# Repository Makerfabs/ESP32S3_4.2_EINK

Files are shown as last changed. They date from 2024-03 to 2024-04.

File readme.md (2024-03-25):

# ESP32 S3 4.2" EINK

```

Version:    V1.0
Author:     Vincent
Create Date:    2024/3/25
Note:

```
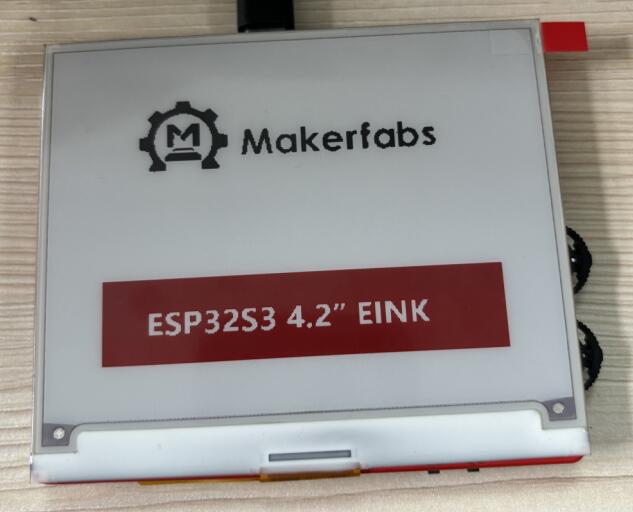
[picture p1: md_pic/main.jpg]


[toc]

# Makerfabs

[Makerfabs home page](https://www.makerfabs.com/)

[Makerfabs Wiki](https://wiki.makerfabs.com/)

# ESP32 S3 4.2" EINK
## Intruduce

Product Link ：[]() 

Wiki Link : []()

The red and black ink screen uses the ESP32S3 driver, contains an SD card slot and two three-way toggle switches.

## Feature

- Integrated ESP32 S3 2.4G WiFi and Bluetooth
- Input Voltage: 3.7V Battery or 5.0V Type-C
- Resolution: 400 * 300
- Display Color: Red / Black and White

# Code

## Compiler Options

- Use type-c use cable connect USB-TTL to PC.
- Select "ESP32 S3 DEV Module"

Libraries:
- Use 2.0.0   FS
- Use 2.0.0   Wire
- Use 1.0.0   esp32-waveshare-epd
- Use 2.0.0   SD_MMC

We used the ink screen driver provided by Waveshare and modified the pins to fit our hardware.

## Example

### fw_test

Factory firmware.
Refresh the solid color page, display the makerfabs Logo, display simple text and multi-color test, and display TF card capacity, press any key to sleep the screen.

### ebook

Read txt file in tf cards, and use switch to change page.

### pic_display

A bmp picture, binary processing, display on the screen.

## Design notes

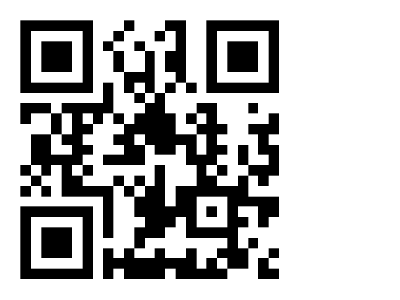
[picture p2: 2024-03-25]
example/pic_display/qr400300.bmp

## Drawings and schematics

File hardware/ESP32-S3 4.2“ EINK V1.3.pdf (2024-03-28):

# BUTTON

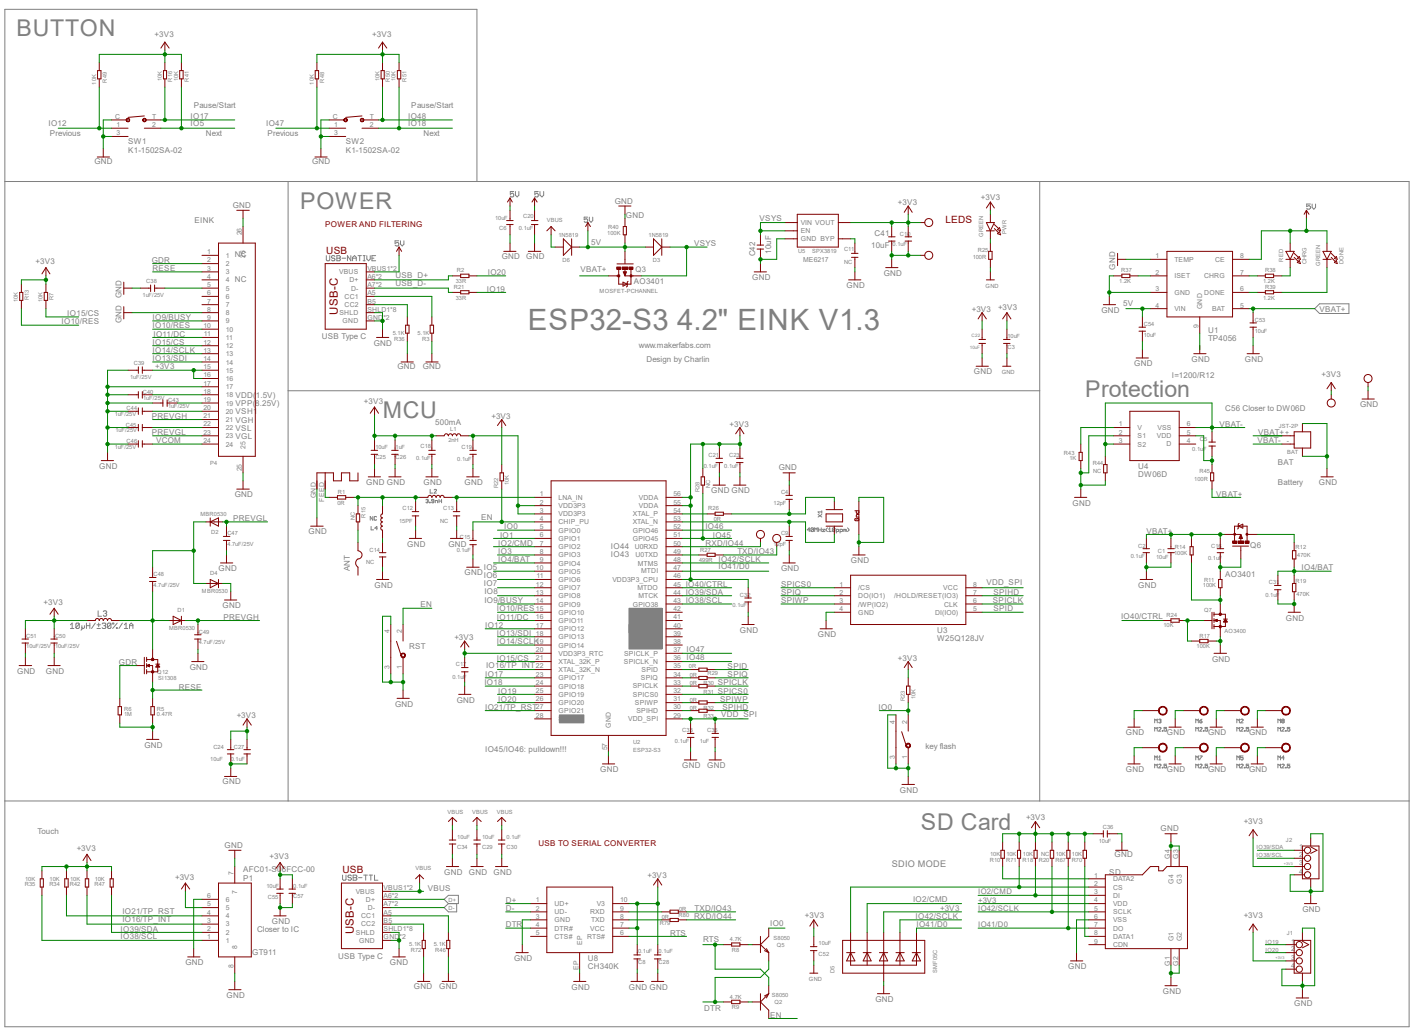
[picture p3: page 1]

LEDS POWER AND FILTERING

USB TO SERIAL CONVERTER

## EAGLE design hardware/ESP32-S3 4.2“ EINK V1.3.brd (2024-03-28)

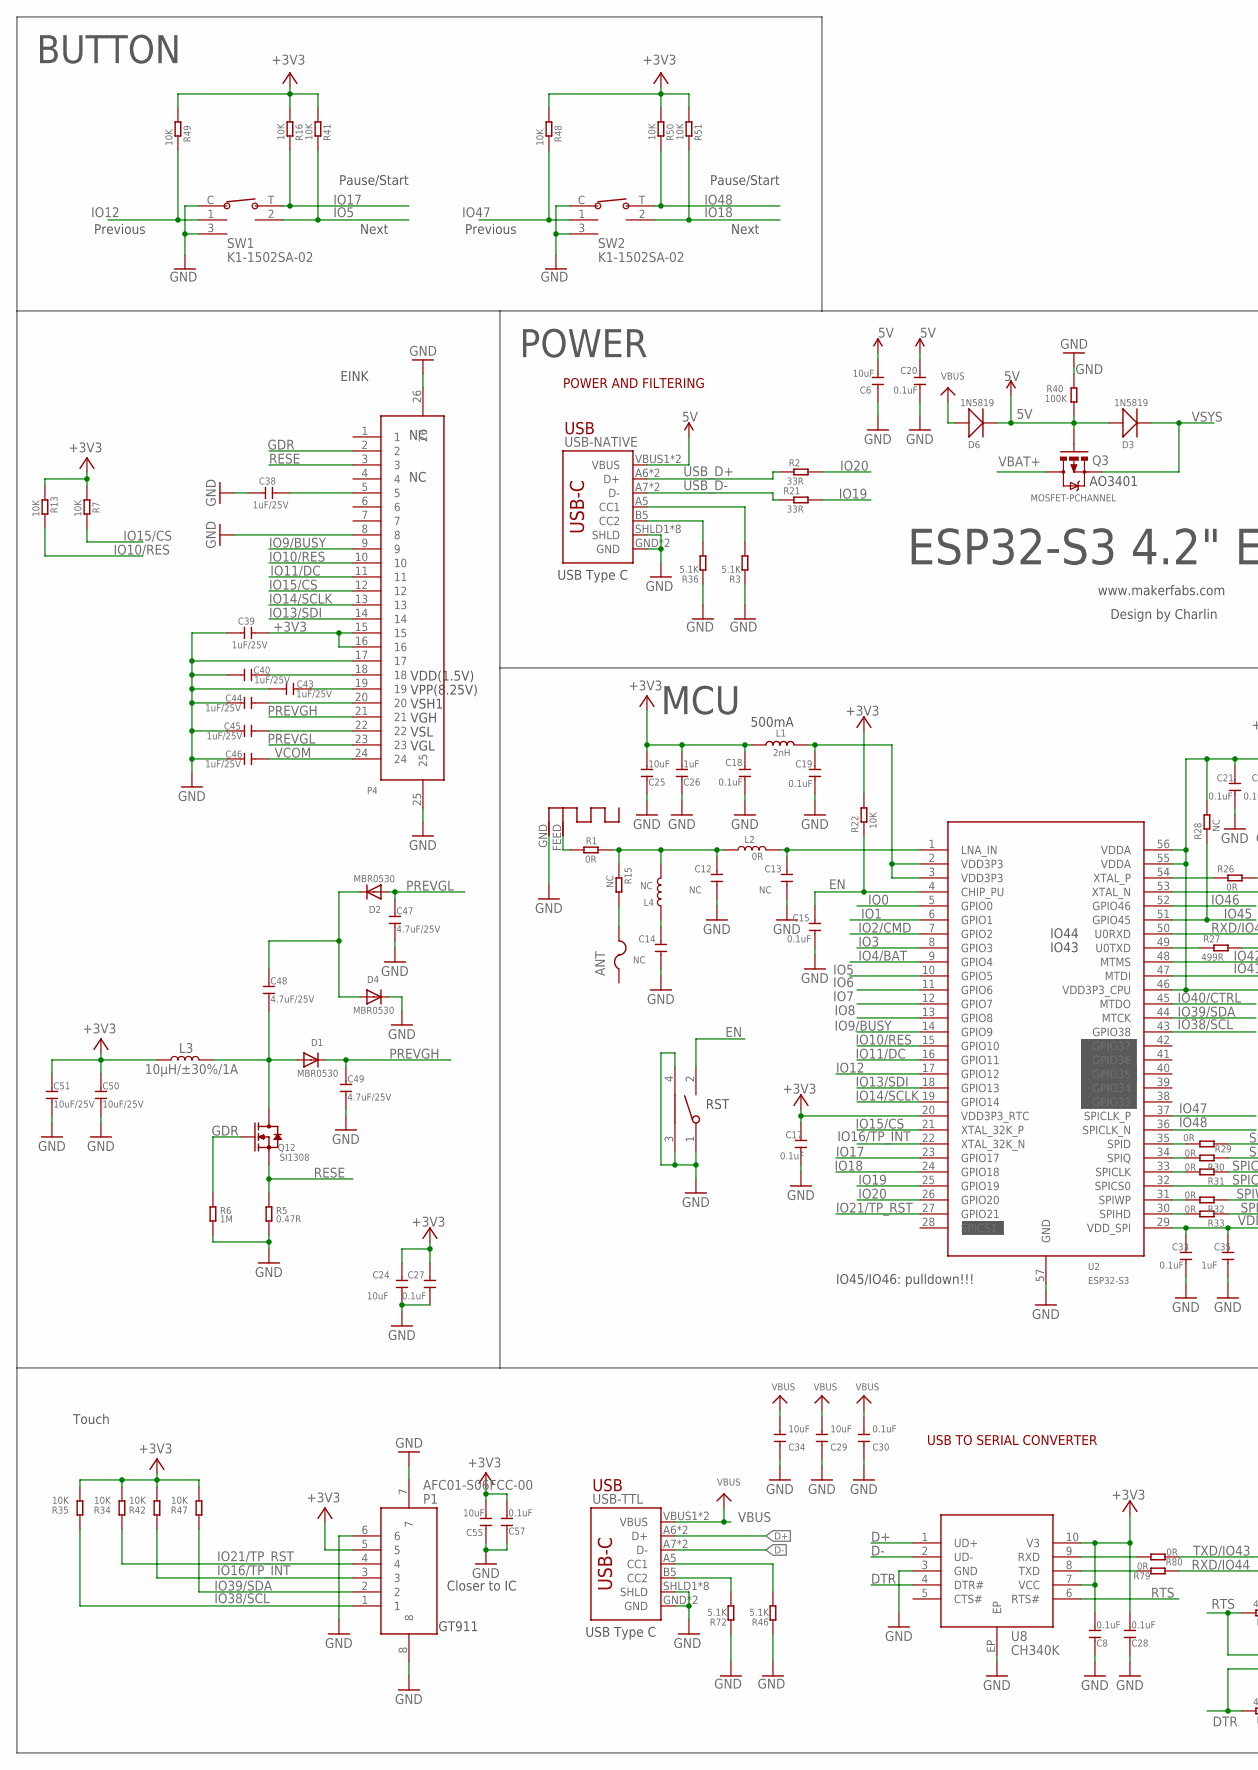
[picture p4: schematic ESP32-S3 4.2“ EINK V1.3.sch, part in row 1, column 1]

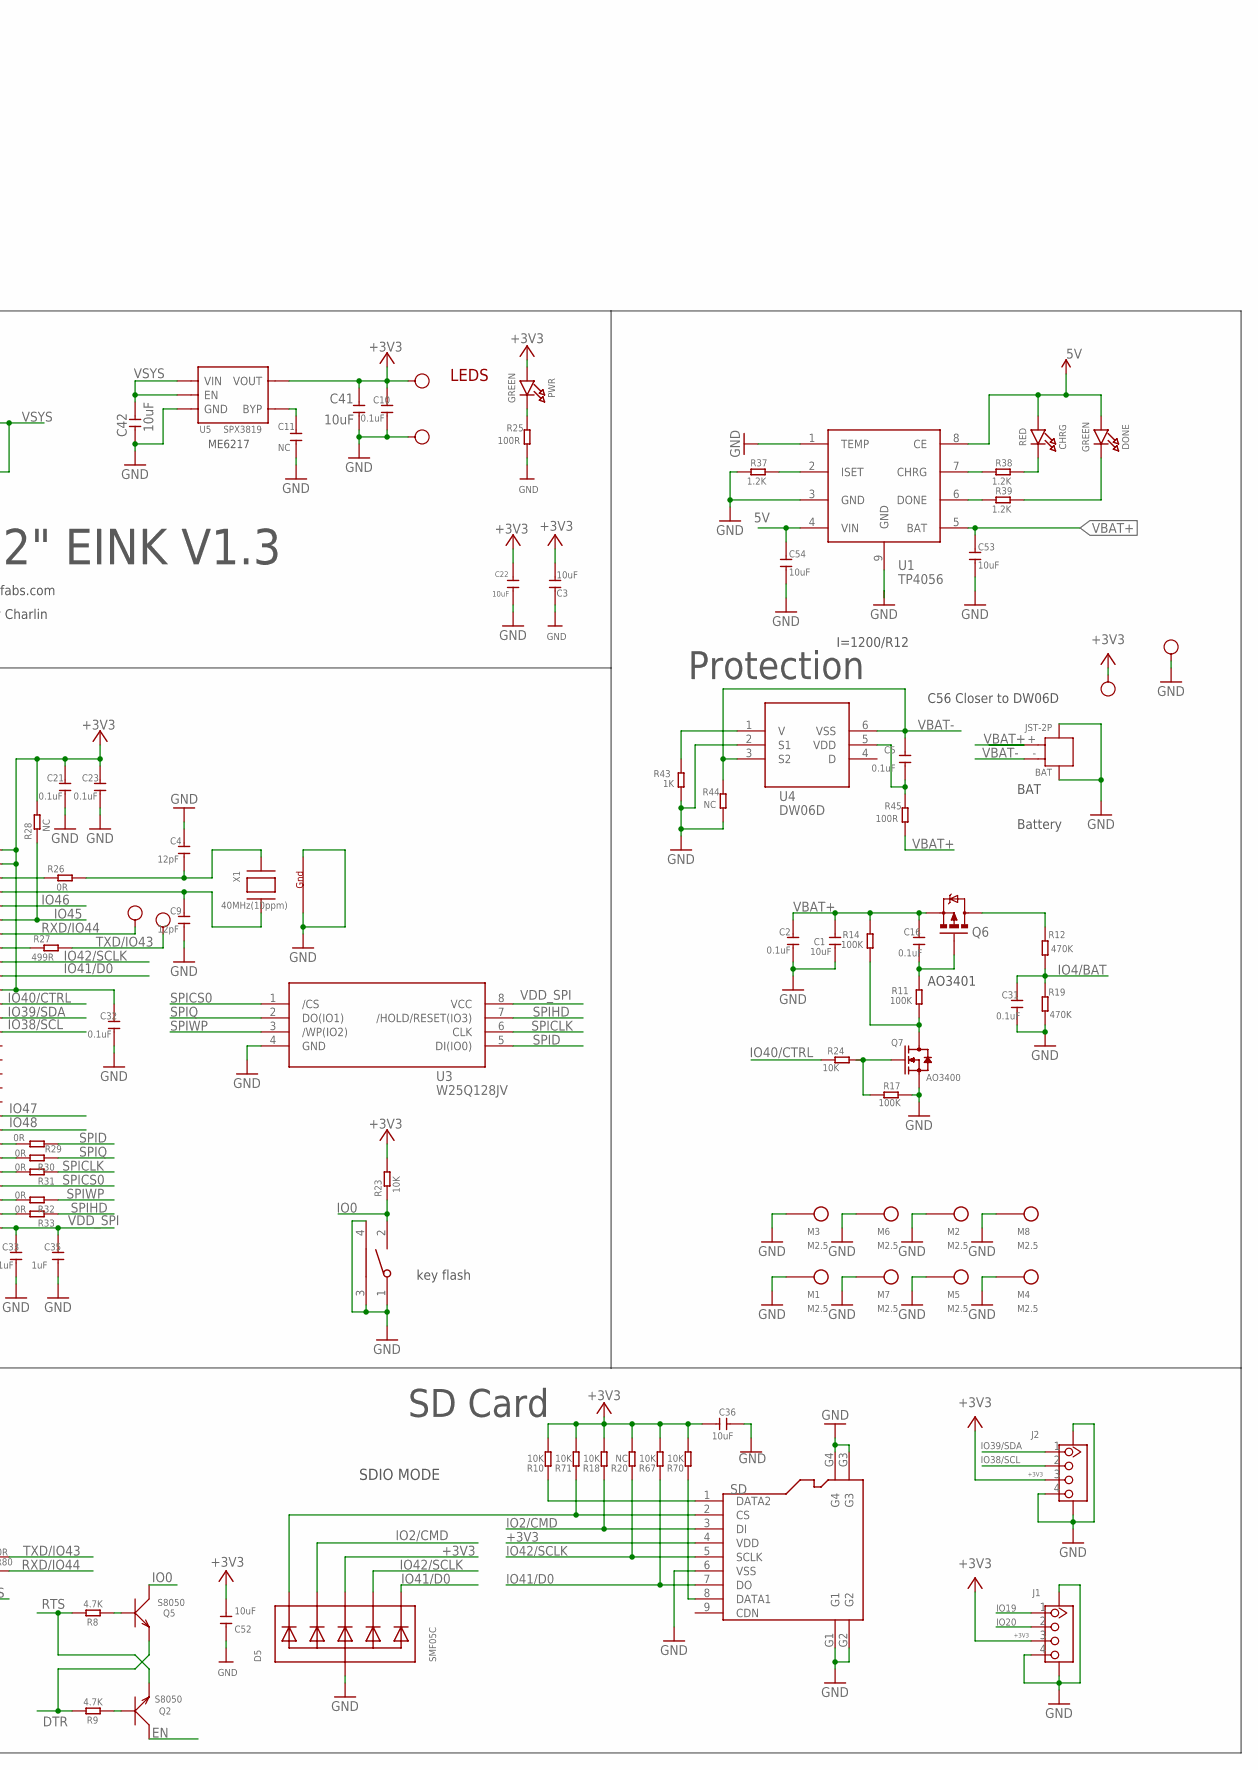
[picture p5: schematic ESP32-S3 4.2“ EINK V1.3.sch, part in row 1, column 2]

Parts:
3V3: TEST-POINT'4545'; TP-D45MIL; PARTNO DNP
ANT: PTCFUSE-1206; R1206
ANT1: ANTENNA; RN-ANT
BAT: JST-2P; HW2-SMD-2.0-90D
C1, C22, C24, C41, C42, C53, C54: 10uF; 0603
C2, C5, C10, C15, C16, C17, C18, C19, C20, C21, C23, C27, C31, C32, C33: 0.1uF; 0603
C3, C6, C25, C29, C34, C36, C52, C55: 10uF; DISCRETE_C0603
C4, C9: 12pF; 0603
C8, C28, C30, C57: 0.1uF; DISCRETE_C0603
C11, C12, C13, C14: NC; 0603
C26: 1uF; DISCRETE_C0603
C35: 1uF; 0603
C38, C39, C40, C43, C44, C45, C46: 1uF/25V; 0603
C47, C48, C49: 4.7uF/25V; 0603
C50, C51: 10uF/25V; 0603
CHRG: RED; CHIPLED_0805_NOOUTLINE
D1, D2, D4: MBR0530; SOD-323F
D3, D6: 1N5819; SOD323
D5: SMF05C; SOT363
DONE: GREEN; CHIPLED_0805_NOOUTLINE
FLASH: TS24CA; 2*4*3.5MM
G: TEST-POINT'4545'; TP-D45MIL; PARTNO DNP
GND: TEST-POINT'4545'; TP-D45MIL; PARTNO DNP
J1, J2: GROVE-CONNECTOR-SMD'90D'; HW4-SMD-2.0-90D
L1: 2nH; DISCRETE_L0603
L2: 0R; 0603
L3: 10µH/±30%/1A; CR54
L4: NC; 0603
M1, M2, M3, M4, M5, M6, M7, M8: M2.5
P1: AFC01-S06FCC-00; SMD8-50P-740L535W
P4: FPC-24P; SMD26-50P-1760L450W
PWR: GREEN; CHIPLED_0805_NOOUTLINE
Q2, Q5: S8050; SOT23
Q3, Q6: MOSFET-PCHANNEL; SOT23-3
Q7: AO3400; DISCRETE_SOT23
Q12: SI1308; SOT23
R1, R26, R29, R30, R31, R32, R33, R79, R80: 0R; R0603
R2, R21: 33R; R0603
R3, R36, R46, R72: 5.1K; DISCRETE_R0603
R5: 0.47R; R0603
R6: 1M; R0603
R7, R13, R16, R22, R23, R24, R41, R48, R49, R50, R51: 10K; R0603
R8, R9: 4.7K; R0603
R10, R18, R34, R35, R42, R47, R67, R70, R71: 10K; DISCRETE_R0603
R11, R14, R17, R40: 100K; R0603
R12, R19: 470K; R0603
R15, R28, R44: NC; R0603
R20: NC; DISCRETE_R0603
R25, R45: 100R; R0603
R27: 499R; R0603
R37, R38, R39: 1.2K; R0603
R43: 1K; R0603
RST: TS24CA; 2*4*3.5MM
RX: TEST-POINT'4545'; TP-D45MIL; PARTNO DNP
SD: HOLDER-MICROSD-9P; 9P-SMD-W/-RING
SW1, SW2: K1-1502SA-02; SMD5-60P-1180L1170W
TX: TEST-POINT'4545'; TP-D45MIL; PARTNO DNP
U1: TP4056; SOP8-1.27P
U2: ESP32-S3; QFN56-7*7MM
U3: W25Q128JV; SOIC-8-208MIL
U4: DW06D; SOT-23-6
U5: SPX3819; SOT23-5
U8: CH340K; ESOP-10-EP-150MIL
USB-NATIVE: USB_C5; USB-C-16P-5
USB-TTL: USB_C5; USB-C-16P-5
V: TEST-POINT'4545'; TP-D45MIL; PARTNO DNP
X1: 40MHz(10ppm); NX3225

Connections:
5V: C6.2, C20.2, C54.1, CHRG.A, D3.+, D6.-, DONE.A, Q3.1 (G), R40.1, U1.4 (VIN), U1.8 (CE), USB-NATIVE.VBUS1 (VBUS), USB-NATIVE.VBUS2 (VBUS)
+3V3: 3V3.T, C3.2, C8.2, C10.2, C17.2, C18.2, C21.2, C22.1, C23.2, C24.2, C25.2, C26.2, C27.2, C28.2, C32.2, C36.2, C39.1, C41.2, C50.1, C51.1, C52.2, C55.2, C57.2, D5.4 (C3), J1.3, J2.3, L1.1, L3.P$1 (1), P1.5, P4.15, P4.16, PWR.A, R7.1, R10.2, R13.1, R16.1, R18.2, R20.2, R22.2, R23.2, R28.2, R34.2, R35.2, R41.1, R42.2, R47.2, R48.1, R49.1, R50.1, R51.1, R67.2, R70.2, R71.2, SD.4 (VDD), U2.20 (VDD3P3_RTC), U2.46 (VDD3P3_CPU), U2.55 (VDDA), U2.56 (VDDA), U5.5 (VOUT), U8.7 (VCC), U8.10 (V3), V.T
D+: U8.1 (UD+), USB-TTL.A6 (D+), USB-TTL.B6 (D+)
D-: U8.2 (UD-), USB-TTL.A7 (D-), USB-TTL.B7 (D-)
DONE: R39.2, U1.6 (DONE)
DTR: Q5.2 (E), R9.2, U8.4 (DTR#)
EN: C15.2, Q2.3 (C), R22.1, RST.2, U2.4 (CHIP_PU)
GDR: P4.2, Q12.1 (G), R6.1
GND: ANT1.GND, BAT.3, BAT.4, C1.1, C2.1, C3.1, C4.2, C6.1, C8.1, C9.1, C10.1, C11.1, C12.1, C13.1, C14.1, C15.1, C17.1, C18.1, C19.1, C20.1, C21.1, C22.2, C23.1, C24.1, C25.1, C26.1, C27.1, C28.1, C29.1, C30.1, C31.1, C32.1, C33.1, C34.1, C35.1, C36.1, C38.2, C39.2, C40.2, C41.1, C42.1, C43.2, C44.2, C45.2, C46.2, C47.2, C49.2, C50.2, C51.2, C52.1, C53.2, C54.2, C55.1, C57.1, D4.C, D5.2 (A), FLASH.1, FLASH.3, FLASH.4, G.T, GND.T, J1.4, J1.SS1, J1.SS2, J2.4, J2.SS1, J2.SS2, M1.1, M2.1, M3.1, M4.1, M5.1, M6.1, M7.1, M8.1, P1.6, P1.7, P1.8, P4.8, P4.17, P4.25, P4.26, Q7.2 (S), R3.1, R5.2, R6.2, R17.1, R19.1, R25.1, R36.1, R37.2, R40.2, R43.1, R44.1, R46.1, R72.1, RST.1, RST.3, RST.4, SD.6 (VSS), SD.G1, SD.G2, SD.G3, SD.G4, SW1.3, SW1.C, SW2.3, SW2.C, U1.1 (TEMP), U1.3 (GND), U1.9 (GND), U2.57 (GND), U3.4 (GND), U4.2 (S1), U5.2 (GND), U8.3 (GND), U8.EP, USB-NATIVE.GND, USB-NATIVE.GND2 (GND), USB-NATIVE.SHLD1 (SHLD), USB-NATIVE.SHLD2 (SHLD), USB-NATIVE.SHLD3 (SHLD), USB-NATIVE.SHLD4 (SHLD), USB-NATIVE.SHLD5 (SHLD), USB-NATIVE.SHLD6 (SHLD), USB-NATIVE.SHLD7 (SHLD), USB-NATIVE.SHLD8 (SHLD), USB-TTL.GND, USB-TTL.GND2 (GND), USB-TTL.SHLD1 (SHLD), USB-TTL.SHLD2 (SHLD), USB-TTL.SHLD3 (SHLD), USB-TTL.SHLD4 (SHLD), USB-TTL.SHLD5 (SHLD), USB-TTL.SHLD6 (SHLD), USB-TTL.SHLD7 (SHLD), USB-TTL.SHLD8 (SHLD), X1.2 (G2), X1.4 (G1)
IO0: FLASH.2, Q5.3 (C), R23.1, U2.5 (GPIO0)
IO1: U2.6 (GPIO1)
IO2/CMD: D5.3 (C2), R18.1, SD.3 (DI), U2.7 (GPIO2)
IO3: U2.8 (GPIO3)
IO4/BAT: C31.2, R12.1, R19.2, U2.9 (GPIO4)
IO5: R41.2, SW1.2, U2.10 (GPIO5)
IO6: U2.11 (GPIO6)
IO7: U2.12 (GPIO7)
IO8: U2.13 (GPIO8)
IO9/BUSY: P4.9, U2.14 (GPIO9)
IO10/RES: P4.10, R13.2, U2.15 (GPIO10)
IO11/DC: P4.11, U2.16 (GPIO11)
IO12: R49.2, SW1.1, U2.17 (GPIO12)
IO13/SDI: P4.14, U2.18 (GPIO13)
IO14/SCLK: P4.13, U2.19 (GPIO14)
IO15/CS: P4.12, R7.2, U2.21 (XTAL_32K_P)
IO16/TP_INT: P1.3, R42.1, U2.22 (XTAL_32K_N)
IO17: R16.2, SW1.T, U2.23 (GPIO17)
IO18: R51.2, SW2.2, U2.24 (GPIO18)
IO19: J1.1, R21.2, U2.25 (GPIO19)
IO20: J1.2, R2.2, U2.26 (GPIO20)
IO21/TP_RST: P1.4, R34.1, U2.27 (GPIO21)
IO38/SCL: J2.2, P1.1, R35.1, U2.43 (GPIO38)
IO39/SDA: J2.1, P1.2, R47.1, U2.44 (MTCK)
IO40/CTRL: R24.2, U2.45 (MTDO)
IO41/D0: D5.6 (C5), R67.1, SD.7 (DO), U2.47 (MTDI)
IO42/SCLK: D5.5 (C4), R20.1, SD.5 (SCLK), U2.48 (MTMS)
IO45: R28.1, U2.51 (GPIO45)
IO46: U2.52 (GPIO46)
IO47: R48.2, SW2.1, U2.37 (SPICLK_P)
IO48: R50.2, SW2.T, U2.36 (SPICLK_N)
ISET: R37.1, U1.2 (ISET)
unnamed: C38.1, P4.5
unnamed: ANT1.FEED, R1.1
unnamed: C16.1, Q6.1 (G), R11.2
unnamed: C43.1, P4.19
unnamed: C44.1, P4.20
unnamed: R3.2, USB-NATIVE.A5 (CC1)
unnamed: PWR.C, R25.2
unnamed: Q2.1 (B), R9.1
unnamed: C45.1, P4.22
unnamed: Q6.3 (D), R12.2
unnamed: C48.1, D2.C, D4.A
unnamed: Q5.1 (B), R8.1
unnamed: R79.2, U8.8 (TXD)
unnamed: R36.2, USB-NATIVE.B5 (CC2)
unnamed: Q7.3 (D), R11.1, R14.1
unnamed: R10.1, SD.1 (DATA2)
unnamed: R46.2, USB-TTL.A5 (CC1)
unnamed: R72.2, USB-TTL.B5 (CC2)
unnamed: Q7.1 (G), R17.2, R24.1
unnamed: R70.1, SD.8 (DATA1)
unnamed: C40.1, P4.18
unnamed: DONE.C, R39.1
unnamed: R38.2, U1.7 (CHRG)
unnamed: ANT.2, R15.2
unnamed: D5.1 (C1), R71.1, SD.2 (CS)
unnamed: CHRG.C, R38.1
unnamed: C5.1, R45.2, U4.5 (VDD)
unnamed: R43.2, U4.1 (V)
unnamed: C12.2, L2.1, L4.2, R1.2, R15.1
unnamed: C13.2, L2.2, U2.1 (LNA_IN)
unnamed: R29.2, U2.35 (SPID)
unnamed: C19.2, L1.2, U2.2 (VDD3P3), U2.3 (VDD3P3)
unnamed: C14.2, L4.1
unnamed: R30.2, U2.34 (SPIQ)
unnamed: R80.2, U8.9 (RXD)
unnamed: R26.1, U2.54 (XTAL_P)
unnamed: R31.2, U2.33 (SPICLK)
unnamed: R32.2, U2.31 (SPIWP)
unnamed: R33.2, U2.30 (SPIHD)
unnamed: R27.1, U2.49 (U0TXD)
unnamed: C9.2, U2.53 (XTAL_N), X1.3 (X2)
unnamed: C4.1, R26.2, X1.1 (X1)
unnamed: C48.2, D1.A, L3.P$2 (2), Q12.3 (D)
unnamed: C11.2, U5.4 (BYP)
PREVGH: C49.1, D1.C, P4.21
PREVGL: C47.1, D2.A, P4.23
RESE: P4.3, Q12.2 (S), R5.1
RTS: Q2.2 (E), R8.2, U8.6 (RTS#)
RXD/IO44: R79.1, RX.T, U2.50 (U0RXD)
SPICLK: R31.1, U3.6 (CLK)
SPICS0: U2.32 (SPICS0), U3.1 (/CS)
SPID: R29.1, U3.5 (DI(IO0))
SPIHD: R33.1, U3.7 (/HOLD/RESET(IO3))
SPIQ: R30.1, U3.2 (DO(IO1))
SPIWP: R32.1, U3.3 (/WP(IO2))
TXD/IO43: R27.2, R80.1, TX.T
USB_D+: R2.1, USB-NATIVE.A6 (D+), USB-NATIVE.B6 (D+)
USB_D-: R21.1, USB-NATIVE.A7 (D-), USB-NATIVE.B7 (D-)
VBAT+: BAT.+ (1), C1.2, C2.2, C16.2, C53.1, Q3.3 (D), Q6.2 (S), R14.2, R45.1, U1.5 (BAT)
VBAT-: BAT.- (2), C5.2, R44.2, U4.3 (S2), U4.6 (VSS)
VBUS: C29.2, C30.2, C34.2, D6.+, USB-TTL.VBUS1 (VBUS), USB-TTL.VBUS2 (VBUS)
VCOM: C46.1, P4.24
VDD_SPI: C33.2, C35.2, U2.29 (VDD_SPI), U3.8 (VCC)
VSYS: C42.2, D3.-, Q3.2 (S), U5.1 (VIN), U5.3 (EN)

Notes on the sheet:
www.makerfabs.com
Design by Charlin
LEDS
POWER AND FILTERING
key flash
POWER
USB
USB Type C
MCU
500mA
ME6217
AO3401
IO45/IO46: pulldown!!!
IO43
IO44
RST
ESP32-S3 4.2" EINK V1.3
EINK
VDD(1.5V)
VPP(8.25V)
VSH1
VGH
VSL
VGL
USB TO SERIAL CONVERTER
SD Card
SDIO MODE
I=1200/R12
Battery
C56 Closer to DW06D
Protection
BAT
GT911
Closer to IC
Touch
Previous
Next
Pause/Start
BUTTON

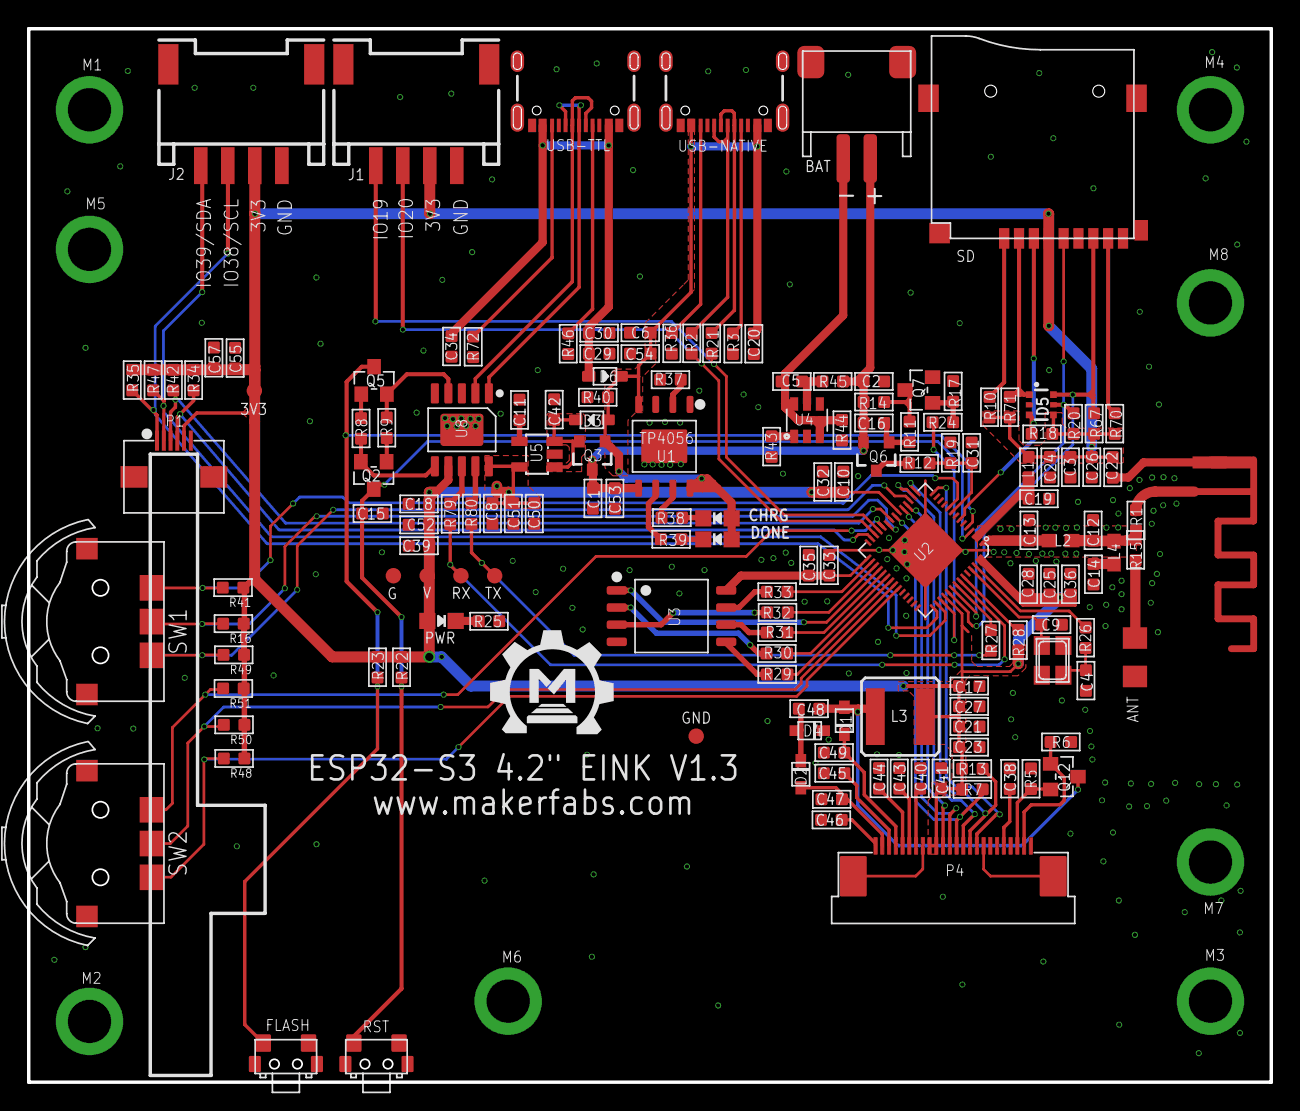
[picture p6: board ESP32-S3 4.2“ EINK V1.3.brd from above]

Board: 2 copper layers, 92.0 x 78.0 mm, 165 parts (0 on the bottom side), 99 nets.

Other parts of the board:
U$1: MAKERFABS_0.3

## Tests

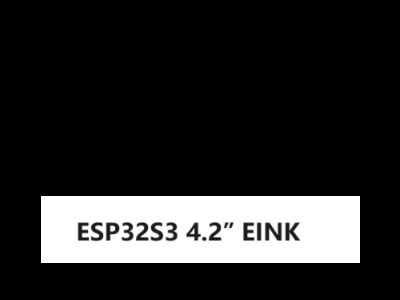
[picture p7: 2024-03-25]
example/fw_test/empty400300.bmp

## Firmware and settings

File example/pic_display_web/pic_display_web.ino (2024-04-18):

#include "DEV_Config.h"
#include "EPD.h"
#include "GUI_Paint.h"
#include <stdlib.h>
#include "FS.h"
#include "SD_MMC.h"
#include <WiFi.h>
#include <WiFiClient.h>
#include <WiFiAP.h>

#define SCREEN_W 400
#define SCREEN_H 300

#define SWITCH_PIN_0 12
#define SWITCH_PIN_1 5
#define SWITCH_PIN_2 17
#define SWITCH_PIN_3 47
#define SWITCH_PIN_4 48
#define SWITCH_PIN_5 18

#define PIN_SD_CMD 2
#define PIN_SD_CLK 42
#define PIN_SD_D0 41

UBYTE *BlackImage, *RYImage; // Red or Yellow
File file;

#define FILE_COUNT 3
int file_count = 0;
String file_list[FILE_COUNT] = {"/1.bmp", "/2.bmp", "/3.bmp"};

int switch_list[6] = {SWITCH_PIN_0, SWITCH_PIN_1, SWITCH_PIN_2, SWITCH_PIN_3, SWITCH_PIN_4, SWITCH_PIN_5};

WiFiServer server(80);

void setup()
{
    hardware_init();

    WiFi.mode(WIFI_AP);
    WiFi.softAP("Makefabs_Eink");
    IPAddress myIP = WiFi.softAPIP();
    USBSerial.print("AP IP address: ");
    USBSerial.println(myIP);

    server.begin();

    eink_init();
    img_task();
}

void loop()
{
    WiFiClient client = server.available(); // listen for incoming clients
    int fresh_flag = 0;

    if (client)
    {                                     // if you get a client,
        USBSerial.println("New Client."); // print a message out the serial port
        String currentLine = "";          // make a String to hold incoming data from the client
        while (client.connected())
        { // loop while the client's connected
            if (client.available())
            {                           // if there's bytes to read from the client,
                char c = client.read(); // read a byte, then
                USBSerial.write(c);     // print it out the serial monitor
                if (c == '\n')
                { // if the byte is a newline character

                    // if the current line is blank, you got two newline characters in a row.
                    // that's the end of the client HTTP request, so send a response:
                    if (currentLine.length() == 0)
                    {
                        // HTTP headers always start with a response code (e.g. HTTP/1.1 200 OK)
                        // and a content-type so the client knows what's coming, then a blank line:
                        client.println("HTTP/1.1 200 OK");
                        client.println("Content-type:text/html");
                        client.println();

                        // the content of the HTTP response follows the header:
                        client.print("Click <a href=\"/H\">here</a> to Change Picture.<br>");

                        // The HTTP response ends with another blank line:
                        client.println();
                        // break out of the while loop:
                        break;
                    }
                    else
                    { // if you got a newline, then clear currentLine:
                        currentLine = "";
                    }
                }
                else if (c != '\r')
                {                     // if you got anything else but a carriage return character,
                    currentLine += c; // add it to the end of the currentLine
                }

                // Check to see if the client request was "GET /H" or "GET /L":
                if (currentLine.endsWith("GET /H"))
                {
                    file_count++;
                    if (file_count > 2)
                        file_count = 0;
                    fresh_flag = 1;

                    client.println("HTTP/1.1 200 OK");
                    client.println("Content-type:text/html");
                    client.println();
                    client.print("Begin to fresh.<br>");
                    client.println();
                }
            }
        }
        // close the connection:
        client.stop();
        USBSerial.println("Client Disconnected.");
    }

    if (fresh_flag == 1)
        img_task();

    if (switch_detect() != -1)
    {
        USBSerial.println("Clear...\r\n");
        EPD_4IN2B_V2_Clear();

        USBSerial.println("Goto Sleep...\r\n");
        EPD_4IN2B_V2_Sleep();

        free(BlackImage);
        free(RYImage);

        BlackImage = NULL;
        RYImage = NULL;
    }
}

void hardware_init()
{
    pinMode(SWITCH_PIN_0, INPUT);
    pinMode(SWITCH_PIN_1, INPUT);
    pinMode(SWITCH_PIN_2, INPUT);

    pinMode(SWITCH_PIN_3, INPUT);
    pinMode(SWITCH_PIN_4, INPUT);
    pinMode(SWITCH_PIN_5, INPUT);

    USBSerial.begin(115200);
    USBSerial.println("EPD_4IN2B_V2_test Demo\r\n");

    SD_MMC.setPins(PIN_SD_CLK, PIN_SD_CMD, PIN_SD_D0);
    if (!SD_MMC.begin("/sdcard", true, true))
    {
        USBSerial.println("Card Mount Failed");
        while (1)
            delay(100);
    }
}

void eink_init()
{
    USBSerial.println("e-Paper Init and Clear...\r\n");
    DEV_Module_Init();
    EPD_4IN2B_V2_Init();
    EPD_4IN2B_V2_Clear();
    DEV_Delay_ms(500);

    // Create a new image cache named IMAGE_BW and fill it with white

    long Imagesize = SCREEN_W * SCREEN_H / 8;
    if ((BlackImage = (UBYTE *)malloc(Imagesize)) == NULL)
    {
        USBSerial.println("Failed to apply for black memory...\r\n");
        while (1)
            ;
    }
    if ((RYImage = (UBYTE *)malloc(Imagesize)) == NULL)
    {
        USBSerial.println("Failed to apply for red memory...\r\n");
        while (1)
            ;
    }
}

void img_task()
{
    USBSerial.println("NewImage:BlackImage and RYImage\r\n");
    Paint_NewImage(BlackImage, SCREEN_W, SCREEN_H, 0, WHITE);
    Paint_NewImage(RYImage, SCREEN_W, SCREEN_H, 0, WHITE);

    // Select Image
    Paint_SelectImage(BlackImage);
    Paint_Clear(WHITE);
    Paint_SelectImage(RYImage);
    Paint_Clear(WHITE);

    print_img_br(SD_MMC, file_list[file_count].c_str(), SCREEN_W, SCREEN_H);

    EPD_4IN2B_V2_Display(BlackImage, RYImage);
}

int switch_detect()
{

    for (int i = 0; i < 6; i++)
    {
        if (digitalRead(switch_list[i]) == 0)
        {
            delay(100);
            if (digitalRead(switch_list[i]) == 0)
            {
                USBSerial.print("Switch Num:");
                USBSerial.println(i);
                return i;
            }
        }
    }

    return -1;
}

// Display image from file
void print_img(fs::FS &fs, String filename, int x, int y)
{
    File f = fs.open(filename, "r");
    if (!f)
    {
        USBSerial.println("Failed to open file for reading");
        f.close();
        return;
    }

    f.seek(54);
    int X = x;
    int Y = y;
    uint8_t RGB[3 * X];
    for (int row = 0; row < Y; row++)
    // for (int row = 0; row < Y; row++)
    {
        f.seek(54 + 3 * X * row);
        f.read(RGB, 3 * X);

        uint8_t temp = 0;
        char index = 0;
        for (int colum = 0; colum < 400; colum++)
        {

            // 判断是否为白色
            if (RGB[colum * 3] > 127)
            {
                // 白色为1
                temp = temp * 2 + 1;
            }
            else
            {
                // 黑色为0
                temp = temp * 2 + 0;
            }

            // temp = 0xf0; 1111 1111

            index++;
            if (index > 7)
            {
                // BlackImage[(X * row + colum) / 8] = temp;
                BlackImage[(X * (299 - row) + colum) / 8] = temp;

                // USBSerial.println(temp);

                temp = 0;
                index = 0;
            }
        }
    }

    f.close();
}

// Display image from file
void print_img_br(fs::FS &fs, String filename, int x, int y)
{
    File f = fs.open(filename, "r");
    if (!f)
    {
        USBSerial.println("Failed to open file for reading");
        f.close();
        return;
    }

    f.seek(54);
    int X = x;
    int Y = y;
    uint8_t RGB[3 * X];
    for (int row = 0; row < Y; row++)
    // for (int row = 0; row < Y; row++)
    {
        f.seek(54 + 3 * X * row);
        f.read(RGB, 3 * X);

        uint8_t temp_black = 0;
        uint8_t temp_red = 0;
        char index = 0;
        for (int colum = 0; colum < 400; colum++)
        {

            // 判断是否为白色 r>200 g>200
            if (RGB[colum * 3] > 150 && RGB[colum * 3 + 2] > 150)
            {
                // 白色为1
                temp_black = temp_black * 2 + 1;
                temp_red = temp_red * 2 + 1;
            }
            // 判断是否为红色 r>200 g<200
            else if (RGB[colum * 3] < 150 && RGB[colum * 3 + 2] > 150)
            {
                temp_black = temp_black * 2 + 1;
                temp_red = temp_red * 2 + 0;
            }
            else
            {
                // 黑色为0
                temp_black = temp_black * 2 + 0;
                temp_red = temp_red * 2 + 1;
            }

            index++;
            if (index > 7)
            {
                BlackImage[(X * (299 - row) + colum) / 8] = temp_black;
                RYImage[(X * (299 - row) + colum) / 8] = temp_red;

                // USBSerial.println(temp);

                temp_black = 0;
                temp_red = 0;
                index = 0;
            }
        }
    }

    f.close();
}

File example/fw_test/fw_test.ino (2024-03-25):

// 使用 1.0.0  版本的库 esp32-waveshare-epd 在文件夹： C:\Users\maker\Documents\Arduino\libraries\esp32-waveshare-epd 
// 使用 2.0.0  版本的库 Wire 在文件夹： C:\Users\maker\AppData\Local\Arduino15\packages\esp32\hardware\esp32\2.0.14\libraries\Wire 
// 使用 2.0.0  版本的库 FS 在文件夹： C:\Users\maker\AppData\Local\Arduino15\packages\esp32\hardware\esp32\2.0.14\libraries\FS 
// 使用 2.0.0  版本的库 SD_MMC 在文件夹： C:\Users\maker\AppData\Local\Arduino15\packages\esp32\hardware\esp32\2.0.14\libraries\SD_MMC 


#include "DEV_Config.h"
#include "EPD.h"
#include "GUI_Paint.h"
#include <stdlib.h>
#include "FS.h"
#include "SD_MMC.h"

extern const unsigned char gImage_black[];
extern const unsigned char gImage_red[];

// #define BUTTON_PIN 0

#define SWITCH_PIN_0 12
#define SWITCH_PIN_1 5
#define SWITCH_PIN_2 17
#define SWITCH_PIN_3 47
#define SWITCH_PIN_4 48
#define SWITCH_PIN_5 18

#define PIN_SD_CMD 2
#define PIN_SD_CLK 42
#define PIN_SD_D0 41

uint64_t cardSize = 0;

int switch_list[6] = {SWITCH_PIN_0, SWITCH_PIN_1, SWITCH_PIN_2, SWITCH_PIN_3, SWITCH_PIN_4, SWITCH_PIN_5};

void setup()
{
    pin_set();

    USBSerial.begin(115200);
    USBSerial.println("EPD_4IN2B_V2_test Demo\r\n");

    DEV_Module_Init();

    USBSerial.println("e-Paper Init and Clear...\r\n");
    EPD_4IN2B_V2_Init();
    EPD_4IN2B_V2_Clear();
    DEV_Delay_ms(500);

    // Create a new image cache named IMAGE_BW and fill it with white
    UBYTE *BlackImage, *RYImage; // Red or Yellow
    UWORD Imagesize = ((EPD_4IN2B_V2_WIDTH % 8 == 0) ? (EPD_4IN2B_V2_WIDTH / 8) : (EPD_4IN2B_V2_WIDTH / 8 + 1)) * EPD_4IN2B_V2_HEIGHT;
    if ((BlackImage = (UBYTE *)malloc(Imagesize)) == NULL)
    {
        USBSerial.println("Failed to apply for black memory...\r\n");
        while (1)
            ;
    }
    if ((RYImage = (UBYTE *)malloc(Imagesize)) == NULL)
    {
        USBSerial.println("Failed to apply for red memory...\r\n");
        while (1)
            ;
    }
    USBSerial.println("NewImage:BlackImage and RYImage\r\n");
    Paint_NewImage(BlackImage, EPD_4IN2B_V2_WIDTH, EPD_4IN2B_V2_HEIGHT, 0, WHITE);
    Paint_NewImage(RYImage, EPD_4IN2B_V2_WIDTH, EPD_4IN2B_V2_HEIGHT, 0, WHITE);

    // Pure Screen
    USBSerial.println("All BLACK\r\n");
    Paint_SelectImage(RYImage);
    Paint_Clear(WHITE);
    Paint_SelectImage(BlackImage);
    Paint_Clear(WHITE);
    Paint_DrawRectangle(0, 0, 400, 300, BLACK, DOT_PIXEL_1X1, DRAW_FILL_FULL);
    EPD_4IN2B_V2_Display(BlackImage, RYImage);
    DEV_Delay_ms(3000);

    USBSerial.println("All RED\r\n");
    Paint_SelectImage(BlackImage);
    Paint_Clear(WHITE);
    Paint_SelectImage(RYImage);
    Paint_Clear(WHITE);
    Paint_DrawRectangle(0, 0, 400, 300, BLACK, DOT_PIXEL_1X1, DRAW_FILL_FULL);
    EPD_4IN2B_V2_Display(BlackImage, RYImage);
    DEV_Delay_ms(3000);

    USBSerial.println("show image for array\r\n");
    EPD_4IN2B_V2_Display(gImage_black, gImage_red);
    DEV_Delay_ms(3000);

    /*Horizontal screen*/
    // 1.Draw black image
    USBSerial.println("Draw black image\r\n");
    Paint_SelectImage(BlackImage);
    Paint_Clear(WHITE);
    Paint_DrawPoint(10, 80, BLACK, DOT_PIXEL_1X1, DOT_STYLE_DFT);
    Paint_DrawPoint(10, 90, BLACK, DOT_PIXEL_2X2, DOT_STYLE_DFT);
    Paint_DrawPoint(10, 100, BLACK, DOT_PIXEL_3X3, DOT_STYLE_DFT);
    Paint_DrawPoint(10, 110, BLACK, DOT_PIXEL_3X3, DOT_STYLE_DFT);
    Paint_DrawLine(20, 70, 70, 120, BLACK, DOT_PIXEL_1X1, LINE_STYLE_SOLID);
    Paint_DrawLine(70, 70, 20, 120, BLACK, DOT_PIXEL_1X1, LINE_STYLE_SOLID);
    Paint_DrawRectangle(20, 70, 70, 120, BLACK, DOT_PIXEL_1X1, DRAW_FILL_EMPTY);
    Paint_DrawRectangle(80, 70, 130, 120, BLACK, DOT_PIXEL_1X1, DRAW_FILL_FULL);
    Paint_DrawString_EN(10, 0, "Makerfabs", &Font16, BLACK, WHITE);
    Paint_DrawNum(10, 50, 987654321, &Font16, WHITE, BLACK);

    // 2.Draw red image
    USBSerial.println("Draw red image\r\n");
    Paint_SelectImage(RYImage);
    Paint_Clear(WHITE);
    Paint_DrawCircle(160, 95, 20, BLACK, DOT_PIXEL_1X1, DRAW_FILL_EMPTY);
    Paint_DrawCircle(210, 95, 20, BLACK, DOT_PIXEL_1X1, DRAW_FILL_FULL);
    Paint_DrawLine(85, 95, 125, 95, BLACK, DOT_PIXEL_1X1, LINE_STYLE_DOTTED);
    Paint_DrawLine(105, 75, 105, 115, BLACK, DOT_PIXEL_1X1, LINE_STYLE_DOTTED);
    Paint_DrawString_EN(10, 20, "hello world", &Font12, WHITE, BLACK);
    Paint_DrawNum(10, 33, 123456789, &Font12, BLACK, WHITE);

    if (sd_check() == 1)
    {
        char s[40];
        sprintf(s, "SD_MMC Size: %lluMB", cardSize);
        Paint_DrawString_EN(10, 200, s, &Font24, WHITE, BLACK);
    }
    else
    {
        Paint_DrawString_EN(10, 200, "SD Card check failed", &Font24, BLACK, WHITE);
    }

    Paint_DrawString_EN(10, 250, "Press Any Switch Sleep", &Font24, BLACK, WHITE);

    USBSerial.println("EPD_Display\r\n");
    EPD_4IN2B_V2_Display(BlackImage, RYImage);
    DEV_Delay_ms(2000);

    free(BlackImage);
    free(RYImage);
    BlackImage = NULL;
    RYImage = NULL;

    while (1)
    {
        if (switch_detect() != -1)
        {
            USBSerial.println("Clear...\r\n");
            EPD_4IN2B_V2_Clear();
            USBSerial.println("Goto Sleep...\r\n");
            EPD_4IN2B_V2_Sleep();

            break;
        }
    }
}

/* The main loop -------------------------------------------------------------*/
void loop()
{
    switch_detect();
    delay(10);
}

void pin_set()
{
    pinMode(SWITCH_PIN_0, INPUT);
    pinMode(SWITCH_PIN_1, INPUT);
    pinMode(SWITCH_PIN_2, INPUT);

    pinMode(SWITCH_PIN_3, INPUT);
    pinMode(SWITCH_PIN_4, INPUT);
    pinMode(SWITCH_PIN_5, INPUT);
}

int switch_detect()
{

    for (int i = 0; i < 6; i++)
    {
        if (digitalRead(switch_list[i]) == 0)
        {
            delay(100);
            if (digitalRead(switch_list[i]) == 0)
            {
                USBSerial.print("Switch Num:");
                USBSerial.println(i);
                return i;
            }
        }
    }

    return -1;
}

int sd_check()
{
    SD_MMC.setPins(PIN_SD_CLK, PIN_SD_CMD, PIN_SD_D0);
    if (!SD_MMC.begin("/sdcard", true, true))
    {
        USBSerial.println("Card Mount Failed");
        return 0;
    }
    uint8_t cardType = SD_MMC.cardType();

    if (cardType == CARD_NONE)
    {
        USBSerial.println("No SD_MMC card attached");
        return 0;
    }

    USBSerial.print("SD_MMC Card Type: ");
    if (cardType == CARD_MMC)
    {
        USBSerial.println("MMC");
    }
    else if (cardType == CARD_SD)
    {
        USBSerial.println("SDSC");
    }
    else if (cardType == CARD_SDHC)
    {
        USBSerial.println("SDHC");
    }
    else
    {
        USBSerial.println("UNKNOWN");
    }

    cardSize = SD_MMC.cardSize() / (1024 * 1024);
    USBSerial.printf("SD_MMC Card Size: %lluMB\n", cardSize);

    return 1;
}

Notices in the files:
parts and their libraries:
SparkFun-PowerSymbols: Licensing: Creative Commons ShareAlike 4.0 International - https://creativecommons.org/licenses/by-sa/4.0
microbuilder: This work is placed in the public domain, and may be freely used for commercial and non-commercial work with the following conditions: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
